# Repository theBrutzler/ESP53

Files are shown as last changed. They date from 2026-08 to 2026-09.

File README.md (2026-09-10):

# ESP53

ESP32-C5 -> ESP01

I created a board, that could fit an ESP32-C5 on a ESP-01 standard pinout. The default ESP01 programer is still working
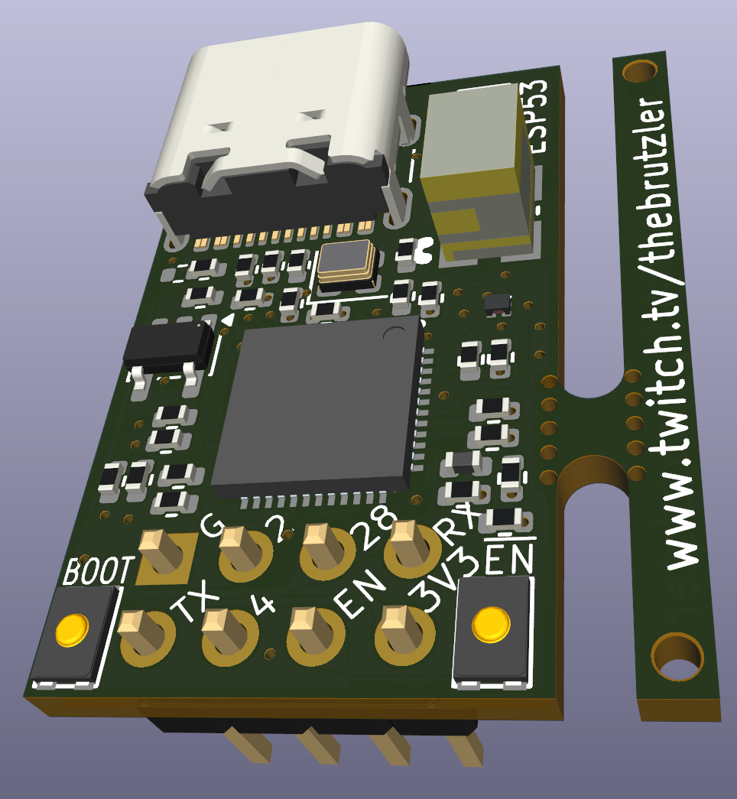
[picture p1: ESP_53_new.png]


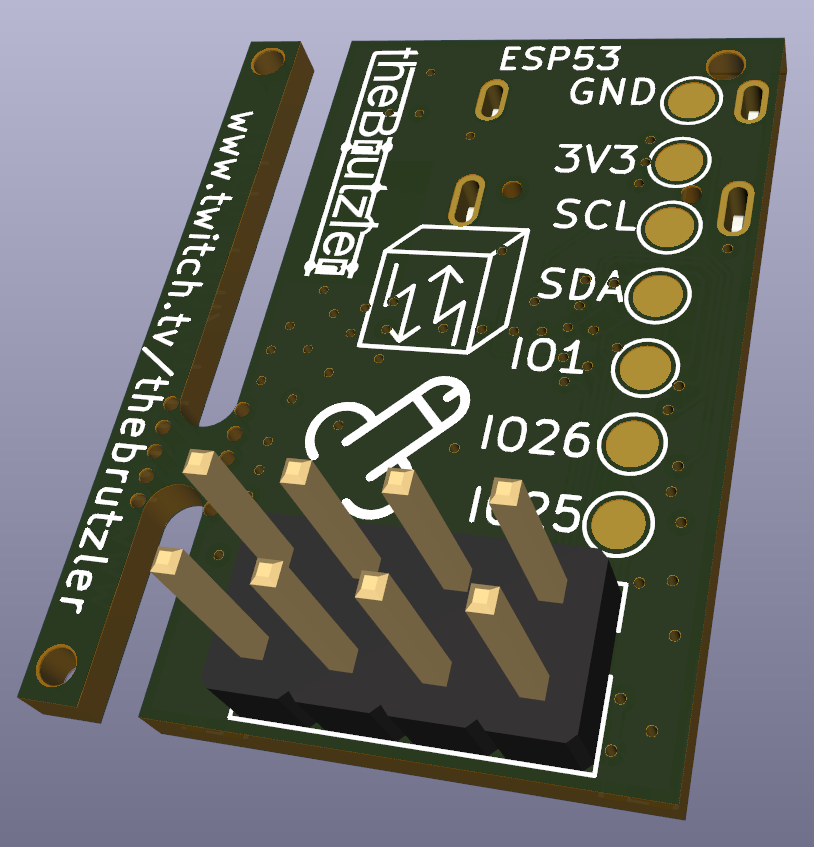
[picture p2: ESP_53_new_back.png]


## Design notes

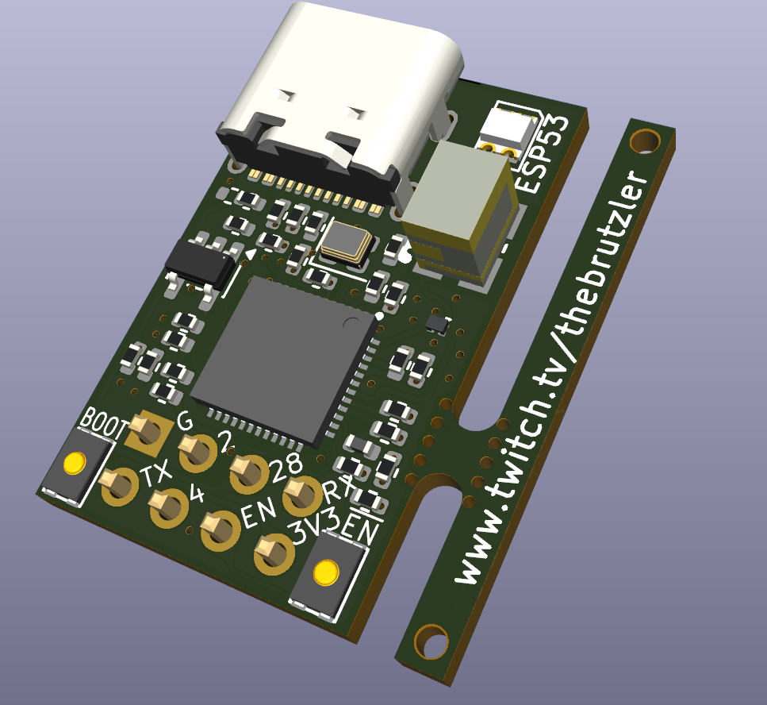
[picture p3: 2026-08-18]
ESP_53.png

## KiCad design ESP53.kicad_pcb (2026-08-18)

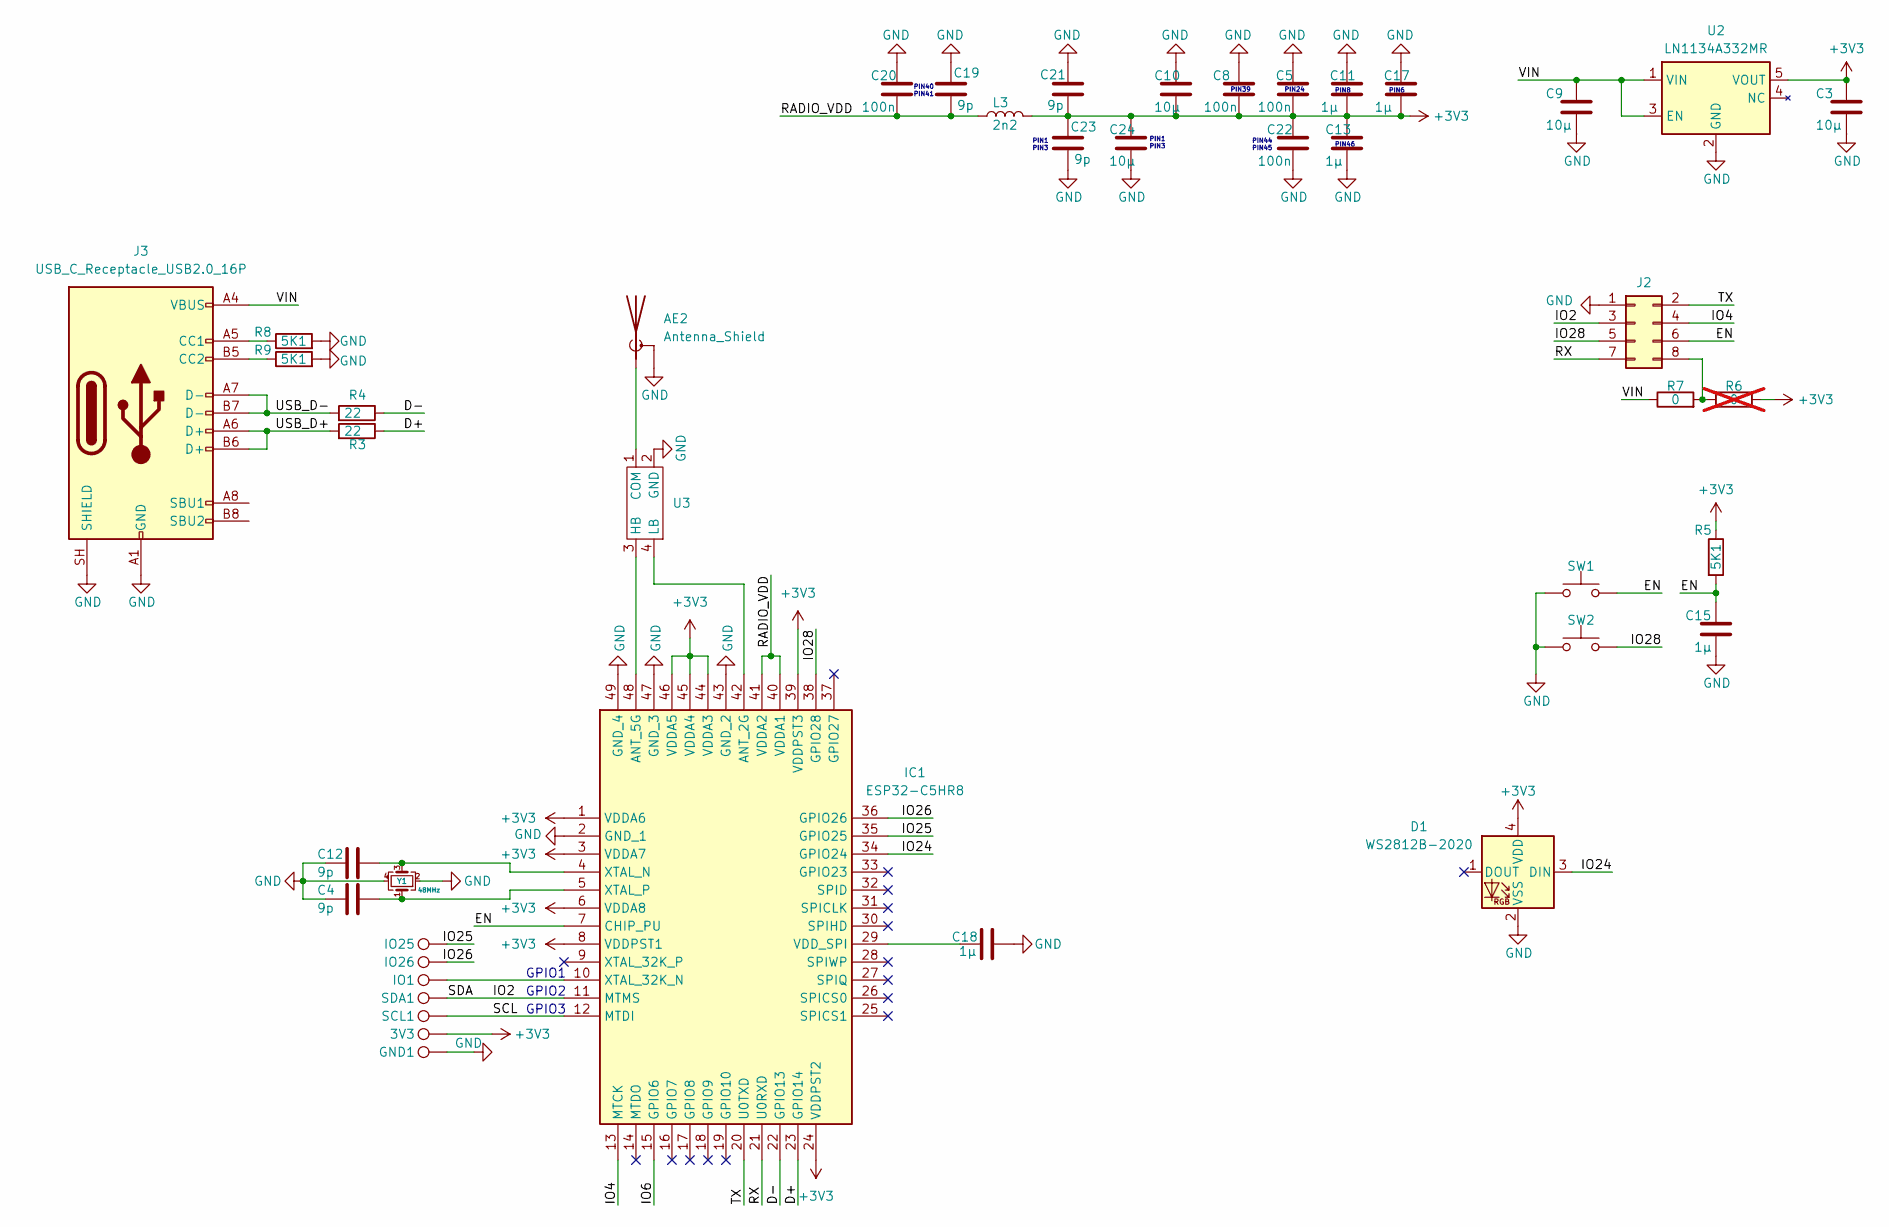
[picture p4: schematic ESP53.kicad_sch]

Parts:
3V3: TestPoint; TestPoint_Pad_D1.5mm
AE2: Antenna_Shield; 2065140001; LCSC C3285113
C3, C9: 10µ; R_0402_1005Metric; LCSC C315248
C4, C12, C19, C21, C23: 9p; R_0402_1005Metric; LCSC C296010
C5, C8, C20, C22: 100n; R_0402_1005Metric; LCSC C1525
C10, C24: 10µ; R_0402_1005Metric; LCSC C48543727
C11, C13, C15, C17, C18: 1µ; R_0402_1005Metric; LCSC C14445
D1: WS2812B-2020; LED_WS2812B-2020_PLCC4_2.0x2.0mm; LCSC C965556
GND1: TestPoint; TestPoint_Pad_D1.5mm
IC1: ESP32-C5HR8; QFN40P600X600X90-49N-D; Manufacturer_Part_Number ESP32-C5HR8; LCSC C51950746
IO1, IO25, IO26: TestPoint; TestPoint_Pad_D1.5mm
J2: Conn_02x04_Odd_Even; PinHeader_2x04_P2.54mm_Vertical
J3: USB_C_Receptacle_USB2.0_16P; USB_C_Receptacle_GCT_USB4105-xx-A_16P_TopMnt_Horizontal; LCSC C54308345
L3: 2n2; L_0402_1005Metric; LCSC C2941466
R3, R4: 22; R_0402_1005Metric; LCSC C25152
R5, R8, R9: 5K1; R_0402_1005Metric; LCSC C25905
R6: 0; R_0402_1005Metric; LCSC C21376; not fitted
R7: 0; R_0402_1005Metric; LCSC C21376
SCL1: TestPoint; TestPoint_Pad_D1.5mm
SDA1: TestPoint; TestPoint_Pad_D1.5mm
SW1, SW2: SW_Push; microswitch; LCSC C100056
U2: LN1134A332MR; TSOT-23-5; LCSC C141419
U3: DIPLEXER; LCSC C432970
Y1: 48MHz; Crystal_SMD_2016-4Pin_2.0x1.6mm; LCSC C50202089

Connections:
+3V3: 3V3.1 (1_1), C3.1, C5.2, C8.2, C10.2, C11.2, C13.1, C17.2, C21.2, C22.1, C23.1, C24.1, D1.4 (VDD), IC1.1 (VDDA6), IC1.3 (VDDA7), IC1.6 (VDDA8), IC1.8 (VDDPST1), IC1.24 (VDDPST2), IC1.39 (VDDPST3), IC1.44 (VDDA3), IC1.45 (VDDA4), IC1.46 (VDDA5), L3.2, R5.1, R6.2, U2.5 (VOUT)
/D+: IC1.23 (GPIO14), R3.1
/D-: IC1.22 (GPIO13), R4.1
/EN: C15.1, IC1.7 (CHIP_PU), J2.6, R5.2, SW1.2
/IO2: IC1.11 (MTMS), J2.3, SDA1.1; also elsewhere on the board
/IO4: IC1.13 (MTCK), J2.4
/IO6: IC1.15 (GPIO6)
/IO24: D1.3 (DIN), IC1.34 (GPIO24)
/IO25: IC1.35 (GPIO25), IO25.1 (1_1)
/IO26: IC1.36 (GPIO26), IO26.1 (1_1)
/IO28: IC1.38 (GPIO28), J2.5, SW2.2
/RADIO_VDD: C19.2, C20.2, IC1.40 (VDDA1), IC1.41 (VDDA2), L3.1
/RX: IC1.21 (U0RXD), J2.7
/SCL: IC1.12 (MTDI), SCL1.1; also elsewhere on the board
/TX: IC1.20 (U0TXD), J2.2
/USB_D+: J3.A6 (D+), J3.B6 (D+), R3.2
/USB_D-: J3.A7 (D-), J3.B7 (D-), R4.2
/VIN: C9.1, J3.A4 (VBUS), J3.A9 (VBUS), J3.B4 (VBUS), J3.B9 (VBUS), R7.1, U2.1 (VIN), U2.3 (EN)
GND: AE2.2 (Shield), C3.2, C4.2, C5.1, C8.1, C9.2, C10.1, C11.1, C12.2, C13.2, C15.2, C17.1, C18.1, C19.1, C20.1, C21.1, C22.2, C23.2, C24.2, D1.2 (VSS), GND1.1, IC1.2 (GND_1), IC1.43 (GND_2), IC1.47 (GND_3), IC1.49 (GND_4), J2.1, J3.A1 (GND), J3.A12 (GND), J3.B1 (GND), J3.B12 (GND), J3.SH (SHIELD), R8.2, R9.2, SW1.1, SW2.1, U2.2 (GND), U3.2 (GND), Y1.2, Y1.4; also elsewhere on the board
unnamed: AE2.1 (A), U3.1 (COM)
unnamed: IC1.42 (ANT_2G), U3.4 (LB)
unnamed: IC1.48 (ANT_5G), U3.3 (HB)
unnamed: C18.2, IC1.29 (VDD_SPI)
unnamed: IC1.10 (XTAL_32K_N), IO1.1 (1_1)
unnamed: C12.1, IC1.4 (XTAL_N), Y1.3
unnamed: C4.1, IC1.5 (XTAL_P), Y1.1
unnamed: J2.8, R6.1, R7.2
unnamed: J3.A5 (CC1), R8.1
unnamed: J3.B5 (CC2), R9.1

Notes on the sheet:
PIN39
PIN1 PIN3
GPIO3
PIN24
GPIO1
PIN8
PIN46
PIN44 PIN45
PIN40 PIN41
GPIO2
PIN6

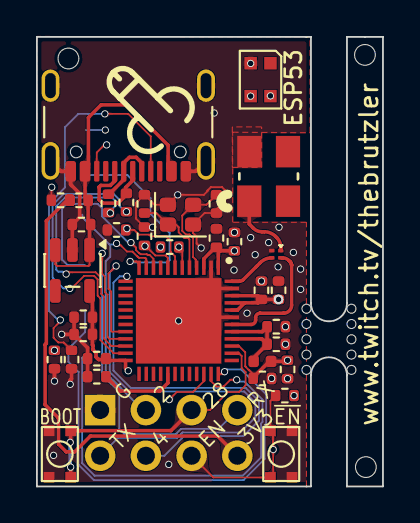
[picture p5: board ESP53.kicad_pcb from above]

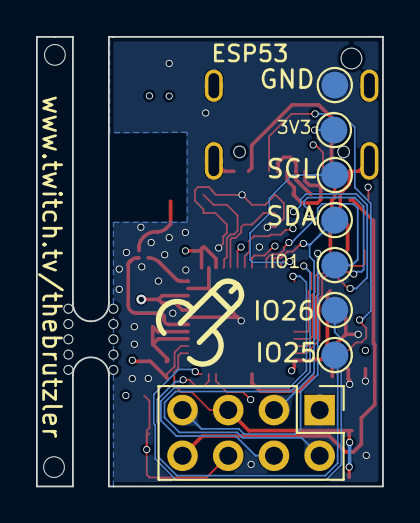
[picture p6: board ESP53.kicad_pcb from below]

Board: 4 copper layers, 19.2 x 25.0 mm, 43 parts (8 on the bottom side), 28 nets.

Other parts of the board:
GND: TestPoint; TestPoint_Pad_D1.5mm
SCL: TestPoint; TestPoint_Pad_D1.5mm
SDA: TestPoint; TestPoint_Pad_D1.5mm

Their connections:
/IO2: SDA.1 (1_1); also elsewhere on the board
/SCL: SCL.1 (1_1); also elsewhere on the board
GND: GND.1 (1_1); also elsewhere on the board

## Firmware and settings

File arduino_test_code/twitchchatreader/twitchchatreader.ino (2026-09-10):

#include <WiFi.h>
#include <WiFiClientSecure.h>

#include <Adafruit_GFX.h>
#include <Adafruit_SSD1306.h>

// --------------------------------------------------
// WLAN
// --------------------------------------------------

const char* WIFI_SSID     = "Internet";
const char* WIFI_PASSWORD = "244466666";

// --------------------------------------------------
// Twitch
// --------------------------------------------------

const char* TWITCH_CHANNEL = "thebrutzler";

// Twitch OAuth Token
// Format: oauth:xxxxxxxxxxxxxxxxxxxxxxxx
const char* TWITCH_OAUTH = "oauth:DEIN_OAUTH_TOKEN";

// Benutzername des Twitch-Accounts,
// zu dem der OAuth-Token gehört
const char* TWITCH_USER = "justinfan0815";

// --------------------------------------------------
// OLED
// --------------------------------------------------

#define SCREEN_WIDTH 128
#define SCREEN_HEIGHT 64

#define OLED_SDA 2
#define OLED_SCL 3

#define OLED_RESET -1
#define OLED_ADDRESS 0x3C

Adafruit_SSD1306 display(
  SCREEN_WIDTH,
  SCREEN_HEIGHT,
  &Wire,
  OLED_RESET
);

// --------------------------------------------------
// Twitch IRC
// --------------------------------------------------

WiFiClientSecure twitch;

String currentUser = "";
String currentMessage = "";

unsigned long lastDisplayUpdate = 0;

// --------------------------------------------------
// Display
// --------------------------------------------------

void displayText(String username, String message)
{
  display.clearDisplay();

  display.setTextColor(SSD1306_WHITE);

  // Benutzername
  display.setTextSize(1);
  display.setCursor(0, 0);

  display.print(username);

  // Trennlinie
  display.drawLine(0, 10, 127, 10, SSD1306_WHITE);

  // Nachricht
  display.setCursor(0, 14);

  // Text automatisch auf mehrere Zeilen verteilen
  int charsPerLine = 21;

  for (int i = 0; i < message.length(); i += charsPerLine)
  {
    String line = message.substring(
      i,
      min(i + charsPerLine, (int)message.length())
    );

    display.println(line);

    if ((i / charsPerLine) >= 4)
      break;
  }

  display.display();
}

// --------------------------------------------------
// Twitch verbinden
// --------------------------------------------------

bool connectTwitch()
{
  Serial.println("Verbinde mit Twitch...");

  // TLS-Zertifikat nicht prüfen
  // Für einen privaten ESP32-Aufbau einfach.
  twitch.setInsecure();

  if (!twitch.connect("irc.chat.twitch.tv", 6697))
  {
    Serial.println("Twitch Verbindung fehlgeschlagen!");
    return false;
  }

  Serial.println("Mit Twitch verbunden.");

  // IRC Login
  twitch.println("PASS " + String(TWITCH_OAUTH));
  twitch.println("NICK " + String(TWITCH_USER));

  // Chat-Kanal aktivieren
  twitch.println("JOIN #" + String(TWITCH_CHANNEL));

  Serial.println("JOIN #" + String(TWITCH_CHANNEL));

  return true;
}

// --------------------------------------------------
// IRC Nachricht verarbeiten
// --------------------------------------------------

void processIRC(String line)
{
  Serial.println(line);

  // Twitch sendet regelmäßig PING
  if (line.startsWith("PING"))
  {
    twitch.println("PONG :tmi.twitch.tv");
    Serial.println("PONG");
    return;
  }

  // Nur PRIVMSG interessiert uns
  if (line.indexOf("PRIVMSG") == -1)
    return;

  // -----------------------------------------------
  // Username extrahieren
  //
  // Beispiel:
  //
  // :username!username@username.tmi.twitch.tv
  // PRIVMSG #thebrutzler :Hallo
  // -----------------------------------------------

  int exclamation = line.indexOf('!');

  if (exclamation < 2)
    return;

  String username = line.substring(1, exclamation);

  // Nachricht beginnt nach " :"
  int messageStart = line.indexOf(" :", line.indexOf("PRIVMSG"));

  if (messageStart == -1)
    return;

  messageStart += 2;

  String message = line.substring(messageStart);

  // -----------------------------------------------
  // Ausgabe
  // -----------------------------------------------

  Serial.println();
  Serial.println("USER: " + username);
  Serial.println("MSG : " + message);
  Serial.println();

  displayText(username, message);
  delay(2000);
}

// --------------------------------------------------
// Setup
// --------------------------------------------------

void setup()
{
  Serial.begin(115200);

  delay(1000);

  // OLED starten
  Wire.begin(OLED_SDA, OLED_SCL);

  if (!display.begin(
        SSD1306_SWITCHCAPVCC,
        OLED_ADDRESS))
  {
    Serial.println("OLED nicht gefunden!");
    while (1)
      delay(1000);
  }

  display.clearDisplay();

  display.setTextColor(SSD1306_WHITE);
  display.setTextSize(1);

  display.setCursor(0, 0);
  display.println("THEBRUTZLER");
  display.println();
  display.println("Verbinde WLAN...");

  display.display();

  // ------------------------------------------------
  // WLAN
  // ------------------------------------------------

  WiFi.begin(WIFI_SSID, WIFI_PASSWORD);

  Serial.print("WLAN");

  while (WiFi.status() != WL_CONNECTED)
  {
    delay(500);
    Serial.print(".");
  }

  Serial.println();
  Serial.println("WLAN verbunden");

  Serial.print("IP: ");
  Serial.println(WiFi.localIP());

  display.clearDisplay();

  display.setCursor(0, 0);
  display.println("THEBRUTZLER");
  display.println();
  display.println("WLAN OK");
  display.println();
  display.println("Twitch...");

  display.display();

  // ------------------------------------------------
  // Twitch
  // ------------------------------------------------

  connectTwitch();

  delay(1000);

  display.clearDisplay();

  display.setCursor(0, 0);
  display.println("THEBRUTZLER");
  display.drawLine(0, 10, 127, 10, SSD1306_WHITE);
  display.setCursor(0, 20);
  display.println("Warte auf Chat...");

  display.display();
}

// --------------------------------------------------
// Loop
// --------------------------------------------------

void loop()
{
  // WLAN-Verbindung prüfen
  if (WiFi.status() != WL_CONNECTED)
  {
    Serial.println("WLAN getrennt!");

    WiFi.reconnect();

    delay(5000);

    return;
  }

  // Twitch-Verbindung prüfen
  if (!twitch.connected())
  {
    Serial.println("Twitch getrennt!");

    display.clearDisplay();
    display.setCursor(0, 0);
    display.println("Twitch");
    display.println();
    display.println("Verbindung");
    display.println("getrennt...");
    display.display();

    delay(3000);

    connectTwitch();

    return;
  }

  // IRC-Daten vorhanden?
  if (twitch.available())
  {
    String line = twitch.readStringUntil('\n');

    line.trim();

    if (line.length() > 0)
    {
      processIRC(line);
    }
  }
}
